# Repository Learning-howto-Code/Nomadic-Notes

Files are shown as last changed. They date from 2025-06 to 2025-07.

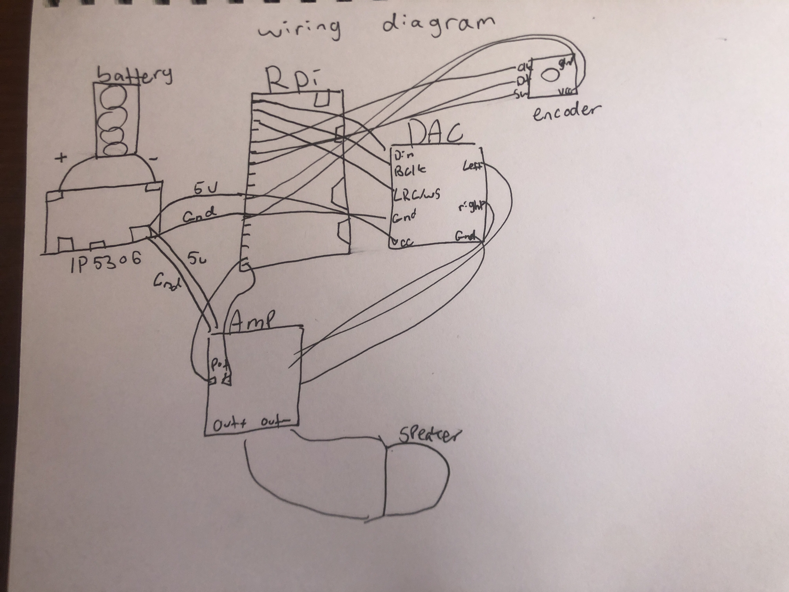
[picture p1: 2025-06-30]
images/wiring_diagram.jpg

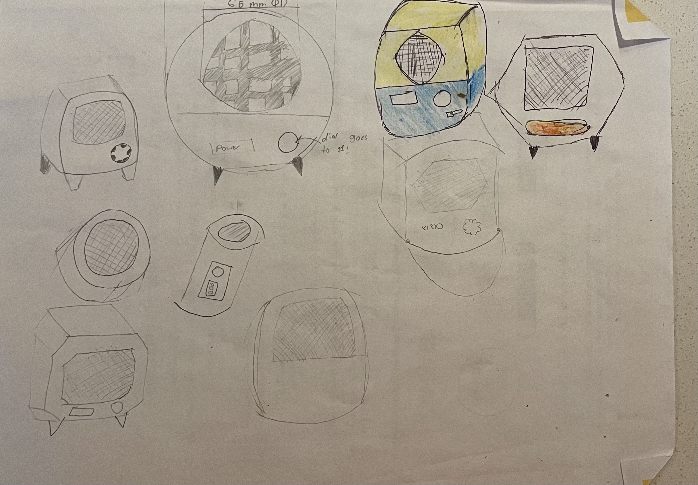
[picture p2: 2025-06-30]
images/sketches.jpg

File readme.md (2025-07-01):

# Nomadic Notes

Nomadic Notes is the first ever pair of open source portable speakers. Nomadic notes are based around a Raspberry Pi Zero 2 W and support the following:

- Airplay  
- Bluetooth Audio  
- Stereo Audio  
- A light, portable design  
- A design-forward approach  

This project is being made for and funded by Hack Club's Highway program.
For any issues or questions, email me at jaketorohopkins@icloud.com, or DM me in the slack at Jake Hopkins
View the BOM in google sheets here for live updates: https://docs.google.com/spreadsheets/d/1EUaRx9kYJ8l8ao9sxJfBVqmWhHC3KokLF9yOrveQJRE/edit?gid=0#gid=0

---

## Renderings
DIY Speakers pre-render
DIY_Speakers V3 render

### Wiring Diagram:

wiring_diagram
(Yes, I drew my wiring diagram, it's also writen out in diagram.md)

---

## BOM (Bill of Materials)

| Item | Quantity | Price (Each) | Link | Notes |
|---|---|---|---|---|
| Rpi Zero 2 W | 2 | $20 | Raspberry Pi Zero 2W with Header | Cheapest board that supports Airplay 2 |
| Speaker | 2 | $26 | Dayton Audio ND65-8 | ~65mm wide |
| DAC | 2 | $5 | Adafruit PCM5100 I2S DAC | Currently out of stock, check Aliexpress |
| Amp | 2 | $20 | MAX9744 | 20W stereo, supports up to 14V |
| Batteries | 8 | $2.50 | Samsung 25R 18650 | On sale, 70% off. 3x4 battery setup |
| Micro SD Card | 2 | $2.50 | — | For Raspberry Pi |
| Buck Converter x5 | 1 pack | $3 | Buck Converter | Comes in a 5-pack |
| Rotary Encoder | 1 | $3 | 2-pack | For volume |
| Battery Charging IC | 2 | $4 | USB-C Charging/BMS Board | De-solder USB-A output ports for load wiring |
| Micro JST Connectors  | 1 pack | $3 | JST Connector | Comes in 10-pack; for driver-to-amp wiring |
| Speaker Grilles (opt) | 1 | $7 | — | Optional but recommended |
| Power Kill Switch | 1 pack | $4 | On/Off Switches | 10-pack on AliExpress |

---

**Check out the BOM excel sheet for the hyperlinks for the exact sources I used and recomend
## Filament

- Your choice

---

### Total Estimated Cost: **$195**
This file was edited for readability by AI as google docs didn't export it well

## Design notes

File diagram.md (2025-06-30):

*Generated pariatly wiht the use of AI to improve Clarity
wiring_diagram

Battery → IP5306

Pack + → B+ pad

Pack – → B– pad

IP5306 → System 5 V

SYS/OUT+ → 5 V rail → Pi VCC (5 V pin) & Amp VCC

SYS/OUT– → common GND

Pi → DAC (I²S)

GPIO 10 (MOSI) → DAC DIN

GPIO 9 (MISO) → DAC not used (keep pull‑down)

GPIO 11 (SCLK) → DAC BCLK

GPIO 18 (PCM‑CLK) → DAC LRC/WS

GND → DAC GND

3.3 V → DAC VCC (if needed)

DAC → MAX9744 Amp

DAC L/R line‑out → AMP L+/R+

DAC GND → AMP GND

Amp → Speaker

AMP OUT+ / OUT– → Speaker ± terminals

Rotary Encoder → Pi

Encoder CLK → Pi GPIO 17 (for example)

Encoder DT → Pi GPIO 27

Encoder SW (push‑button) → Pi GPIO 22

+5 V → Encoder VCC

GND → Encoder GND

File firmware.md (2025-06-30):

I am using shairport sync, so there is no custom firmware. it is based off of this turorial 
https://www.xda-developers.com/build-airplay-receiver-using-raspberry-pi/
Once I get my pot and stuff I will have to wirght a little bit of python but it's very trivial, just reading and writing to 3 gpio pins

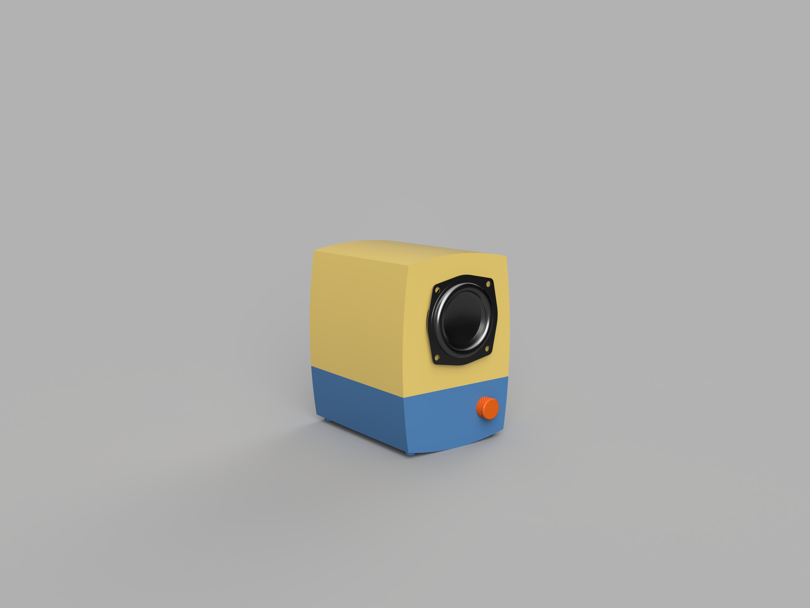
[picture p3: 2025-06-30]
images/DIY_Speakers final renderpng.png

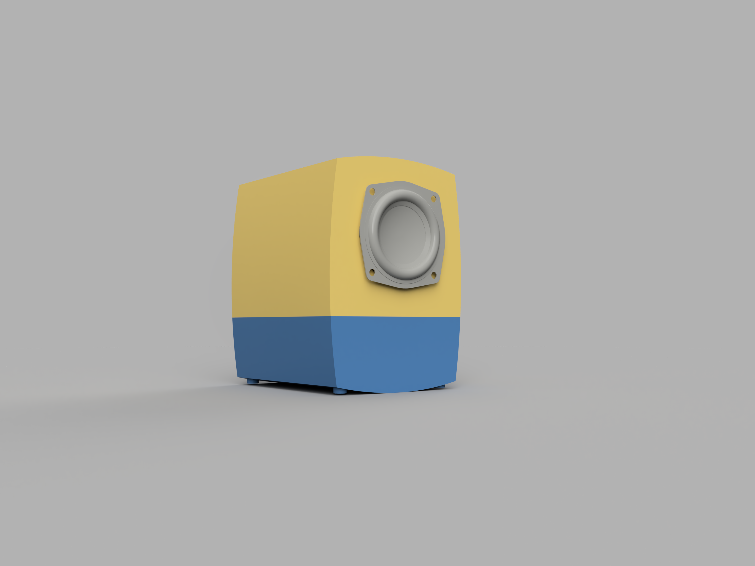
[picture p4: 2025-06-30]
images/DIY_Speakers V3 render.png

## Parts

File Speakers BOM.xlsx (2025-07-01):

Low range~120$ For pair
Item | Quantity | Price(Each) | Link | Notes
Rpi zero 2 W | 2 | 20 | Raspberry Pi Zero 2W with Header (https://www.adafruit.com/product/6008) | cheepest board that supports airplay 2
Speaker | 2 | 26 | Dayton Audio ND65-8 2-1/2" Aluminum Cone Full-Range Neo Driver 8 Ohm (https://www.amazon.com/gp/product/B0042GWIZI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) | From this video, ~ 65mm wide (https://www.youtube.com/watch?v=a43LXqRwQC8&list=PLOJU8YJjFwGOeh6BgCWVhZf5HSkfVPVP3&index=4)
DAC | 2 | 5 | Adafruit PCM5100 I2S DAC with Line Level Output - 100dB SNR (https://www.adafruit.com/product/6251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) | Currently out of stock, check on aliexpress
Amp | 2 | 20 | Stereo 20W Class D Audio Amplifier - MAX9744 (https://www.adafruit.com/product/1752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) | shiping is 6$, comes in 5 days, can take in up to 14 volts
Batteries | 8 | 2.5 | Samsung 25R 18650 2500mAh 20A Battery (https://www.18650batterystore.com/products/samsung-25r-18650?variant=37119890063511) | On sale, 70% off. will do 3x4 battery setup
micro sd card | 2 | 2.5 | Micro SD card (https://www.aliexpress.us/item/3256806796589355.html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) | For Rpi's
Buck converter x5 | 1 | 3 | Buck Converter (https://www.aliexpress.us/item/3256808133588550.html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) | comes in a 5 pack
Rotary Encoder | 1 | 3 | 2 pack (https://www.aliexpress.us/item/3256808610376268.html?pdp_ext_f=%7B%22order%22%3A%22450%22%7D) | for volume
Battery Charging IC | 2 | 4 | Usb-C charging/BMS board (https://www.aliexpress.us/item/2255800387899850.html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) | You need to de-solder the usb-A output ports in order to solder your loads onto them
Micro JST connectors | 1 | 3 | JST connector (https://www.aliexpress.us/item/3256803204628036.html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) | comes in a 10 pack, used for connecting driver to amp, and amp to buck converter
Speaker Grilles(optional) | 1 | 7 | optional grilles (https://www.amazon.com/MEETOOT-Rolled-Loudspeaker-Mounting-Speaker/dp/B09L7LBTGV) | Not necesary, but recomended unless you like the look of the raw speaker cone
power kill switch | 1 | 4 | 10 pack of on/off switches (https://www.aliexpress.us/item/3256808310696141.html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) | This was the cheepest one on Aliexpress
M3 screws | 4 | 50 cents |  | I found them in person at ace or other hardware store
Filament |  |  |  | Your choice
Total |  | 195

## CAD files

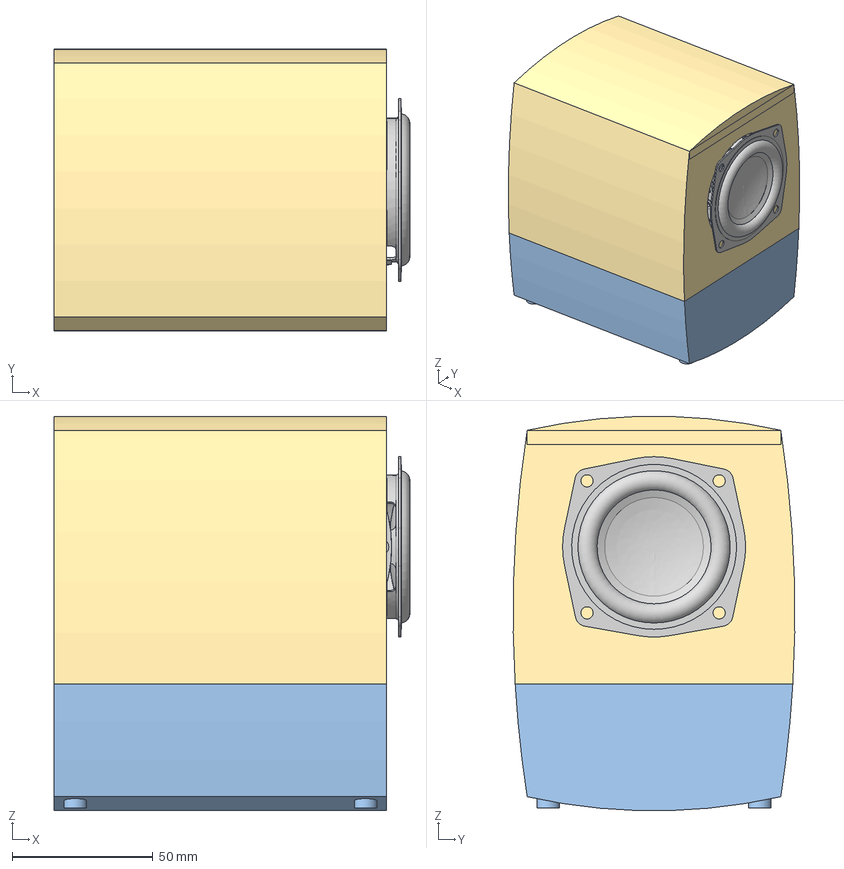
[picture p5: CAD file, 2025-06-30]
CAD_Files/Step/DIY Speakers v4.step
126.2 x 99.9 x 139.8 mm
Speaker Housing
Driver
Driver box
Pot

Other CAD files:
CAD_Files/F3d/DIY Speakers v4.f3d

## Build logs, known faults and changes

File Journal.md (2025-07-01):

## **Total Time Spent:**

## \*I started this project on vacation so for the first few days I didn’t get nearly as much done as you might expect, also I didn’t work on it everyday, so I only included the days I worked on it

# Days 1&2- Gathering intel

	I’ve found that a lot of people 3D print, make pcb’s, and create impressive robotics projects. Some people, especially on youtube create art or even full projects with 3d printing, but very few people create the instructables type projects from a design perspective. Here’s what I mean. If you look online dozens of people have created a weather box for their desk, allowing them to see the weather at a glance. I think this is an awesome project, and will introduce you to electronics, CAD, and integration hell. But they're all just boxes\! For example look at this awesome project by [educ8s on Instructables](https://www.instructables.com/Arduino-ESP32-Color-E-Paper-Weather-Station/). It looks great, and you can really tell that you put a lot of hard work into it. But the actual 3d printed enclosure is quite mundane and is just a box with some light fillets. Just to be clear, I’m not throwing shade on anybody, and especially not educ8s, I think what he did is really cool, but it’s been done before, and not what **I** want to do.  
	So I didn’t. I approached my project from the very beginning as a design project. Yes, there are complicated electronics, enclosures and firmware, but I wanted my project to stand out because it looked good, and for that to be the reason to build it.  
	On days one and two I searched and read nearly every guide on the internet for custom, DIY, portable speakers and a few things stood out to me. Everyone made boomboxes- or at least some version of a big plywood box that housed all the electronics and speakers, meaning that they could never achieve stereo sound nor were they very portable. Also no one made airplay2 speakers. While a proprietary Apple protocol, all of my friends and family, including myself, have iPhones, and if I were to use this speaker regularly it would have to support this super easy way to connect, along with bluetooth. Finally none of them looked good. There were some really nice designs, they weren’t what I was looking for- either they were wood veneer or a retro design. I spent the next few days thinking about how to make my speakers shine.  
 
**Time Spent: \~2 hours**

# Days 3 & 4 \- Ideation

From taking 3d sculpture last year in school I learned a lot about planning out a project, and I think it shows how I approached this project that I started with an element of art, sketches; Thumbnail sketches are an easy way to quickly get your ideas on paper, and I love them as their not inhibited by my art skills. From looking at JBl’s website I already knew that I wanted to put a playful spin on the [JBl clip 5](https://www.jbl.com/bluetooth-speakers/CLIP-5.html). I liked the form factor, but knew that it would be near impossible to fit all of my components into such a small form factor, so I decided to take the playful curves and design language of the clip 5 and put a spin on bookshelf speakers. Starting with the shape of a bookshelf speaker, I first thought about putting heavy chamfers on the corners, as seen in the bottom left corner; I decided against this though as chamfers give more of an industrial feel, and suit metal more, which isn’t what I wanted for this project, even though I think it would look really good. I then questioned the form factor, wondering if a tube-like design like the [Charge 5](https://www.jbl.com/bluetooth-speakers/CLIP-5.html) might be better. I also decided against this though, as it has been done before and doesn’t stand out in the way I want it to. You can see that I then settled in on my final design, although it sort of looks like a minion in this drawing. My final design incorporates lots of swooping arches in order to give my speakers the playful look I was going for. In the drawing I played around with color schemes but decided on black and white with orange accents, all PLA.  
sketches
**Time Spent: \~1.5 hours**

# Days 5 & 6 \- Components Sourcing


	Today I started my [BOM](https://docs.google.com/spreadsheets/d/1EUaRx9kYJ8l8ao9sxJfBVqmWhHC3KokLF9yOrveQJRE/edit?gid=0#gid=0) and sourcing components. After watching videos and reading tutorials I started to get a sense of what components people were using. I finally landed on the Dayton Audio ND65-8 2-1/2" driver from [this video by DIY Perks](https://www.youtube.com/watch?v=a43LXqRwQC8&list=PLOJU8YJjFwGOeh6BgCWVhZf5HSkfVPVP3&index=4&pp=iAQB) as it is a full range driver, eliminating the need for a crossover, while still being quite capable(80-20,000 hertz range). As aforementioned, one of my design requirements was that it had airplay 2, leading me to use a Raspberry Pi 2 W(Rpi) instead of a microcontroller or bluetooth module. The DAC is an important component, since even though the Rpi has built in DAC it’s designed for reading data from the GPIO pins, and isn’t audio grade. I’ve never built a battery pack before, and am deciding to start the CAD first, before sourcing my BMS and charging module.  
**Time Spent\~ 3 hours**

# Days 7 & 8 \- Hoping into CAD
DIY Speakers pre-render

I use Fusion 360, as I find it’s the perfect tool for these types of projects, plus they hook up students with a free license and cloud computer. After calculating the column for the driver box, I built up the enclosure around it. I designed the whole thing to be assembled with M3 screws, and to print without supports. Before finishing the model I decided to source the last components for my battery pack.

*Render of my mostly complete model*  
**Time Spent \~2 hours**

# Day 9- The battery pack

Today I worked on the battery pack for my speakers. I knew that I wanted to use 18650 cells as I had worked with them before and I found out from the slack that [18650batterystore.com](http://18650batterystore.com) is one of the cheapest places to buy legit cells. After doing some basic math I concluded that my speaker would draw a little less that 5 watts at peak power( 2 watts for the Rpi, 2 watts for the driver, plus some loss along the way). I decided on 4 cells in parallel for an output of 3.7 volts nominal at 10 amps, or around 37 watts. This should give the speakers approximately 7 hours of run time- plenty for an all day battery. After looking at battery packs designed by other people I saw [this super simple one by Great Scott.](https://www.instructables.com/Building-a-USB-Type-C-PD-Powerbank-the-Super-Simpl/) I decided to use the charging IC from it since it would safely charge the 18650 cells, stepped the 3.7 volts up to 5 and charged via Usb-C.  
**Time Spent\~1 hour**

# Day 10- Finishing up CAD
DIY_Speakers final renderpng

Today I finished up my CAD design. I added print in place feet to the base of my design and made some other small tweaks. Since I had finalized my battery system I also added things like my rotary encoder and kill switch into the design. Thinking about putting the finishing touches on my design and the acoustic properties of my driver box I studied how high end speakers, like the 2,000$ [Sonus Faber Sonneto’s](https://www.sonusfaber.com/en/products/sonetto-i) use asymmetrical design to dampen resonant frequency and incorporated asymmetrical draft angles into my design to help with frequencies bouncing back and forth between parallel faces. After rendering out my design from a few different angles I was happy with it, and getting ready to submit my project

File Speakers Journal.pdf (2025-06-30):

### Total Time Spent:

### *I started this project on vacation so for the first few days I didn’t get nearly as much done as you might expect, also I didn’t work on it everyday, so I only included the days I worked on it

## Days 1&2- Gathering intel

I’ve found that a lot of people 3D print, make pcb’s, and create impressive robotics projects. Some people, especially on youtube create art or even full projects with 3d printing, but very few people create the instructables type projects from a design perspective. Here’s what I mean. If you look online dozens of people have created a weather box for their desk, allowing them to see the weather at a glance. I think this is an awesome project, and will introduce you to electronics, CAD, and integration hell. But they're all just boxes! For example look at this awesome project by educ8s on Instructables. (https://www.instructables.com/Arduino-ESP32-Color-E-Paper-Weather-Station/) It looks great, and you can really tell that you put a lot of hard work into it. But the actual 3d printed enclosure is quite mundane and is just a box with some light fillets. Just to be clear, I’m not throwing shade on anybody, and especially not educ8s, I think what he did is really cool, but it’s been done before, and not

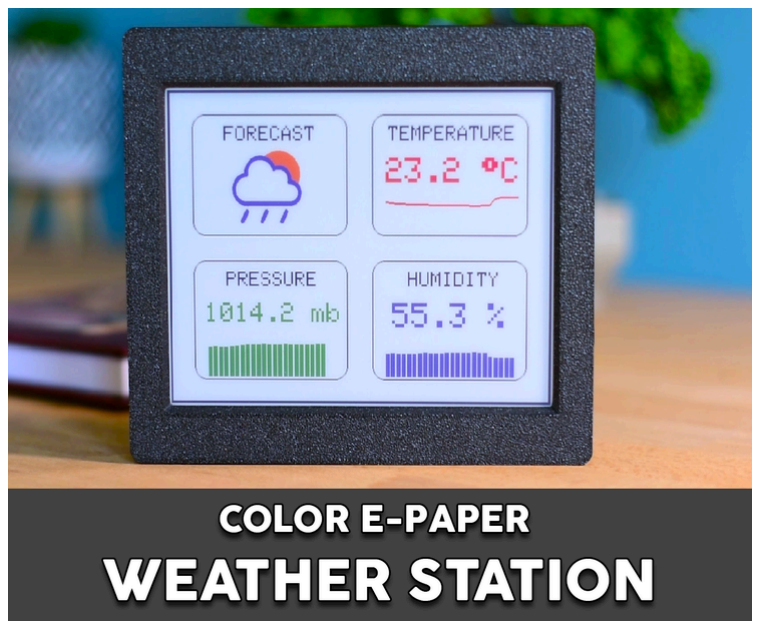
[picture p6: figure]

what I want to do.
So I didn’t. I approached my project from the very beginning as a design project. Yes, there are complicated electronics, enclosures and firmware, but I wanted my project to stand out because it looked good, and for that to be the reason to build it.
On days one and two I searched and read nearly every guide on the internet for custom, DIY, portable speakers and a few things stood out to me. Everyone made boomboxes- or at least some version of a big plywood box that housed all the electronics and speakers, meaning that they could never achieve stereo sound nor were they very portable. Also no one made airplay2 speakers. While a proprietary Apple protocol, all of my friends and family, including myself, have iPhones, and if I were to use this speaker regularly it would have to support this super easy way to connect, along with bluetooth. Finally none of them looked good. There were some really nice designs, they weren’t what I was looking for- either they were wood veneer or a retro design. I spent the next few days thinking about how to make my speakers shine.
Time Spent: ~2 hours

## Days 3 & 4 - Ideation

From taking 3d sculpture last year in school I learned a lot about planning out a project, and I think it shows how I approached this project that I started with an element of art, sketches; Thumbnail sketches are an easy way to quickly get your ideas on paper, and I love them as their not inhibited by my art skills. From looking at JBl’s website I already knew that I wanted to put a playful spin on the JBl clip 5. (https://www.jbl.com/bluetooth-speakers/CLIP-5.html) I liked the form factor, but knew that it would be near impossible to fit all of my components into such a small form factor, so I decided to take the playful curves and design language of the clip 5 and put a spin on bookshelf speakers. Starting with the shape of a bookshelf speaker, I first thought about putting heavy chamfers on the corners, as seen in the bottom left corner; I decided against this though

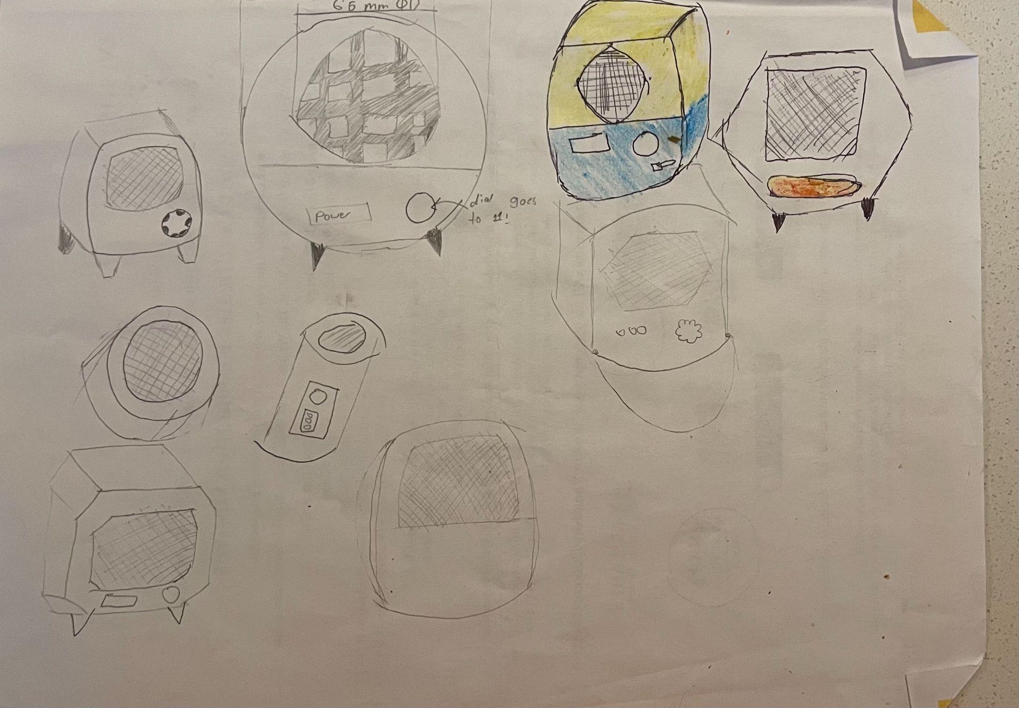
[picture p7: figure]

as chamfers give more of an industrial feel, and suit metal more, which isn’t what I wanted for this project, even though I think it would look really good. I then questioned the form factor, wondering if a tube-like design like the Charge 5 (https://www.jbl.com/bluetooth-speakers/CLIP-5.html) might be better. I also decided against this though, as it has been done before and doesn’t stand out in the way I want it to. You can see that I then settled in on my final design, although it sort of looks like a minion in this drawing. My final design incorporates lots of swooping arches in order to give my speakers the playful look I was going for. In the drawing I played around with color schemes but decided on black and white with orange accents, all PLA.
Time Spent: ~1.5 hours

## Days 5 & 6 - Components Sourcing

Today I started my BOM (https://docs.google.com/spreadsheets/d/1EUaRx9kYJ8l8ao9sxJfBVqmWhHC3KokLF9yOrveQJRE/edit?gid=0#gid=0) and sourcing components. After watching videos and reading tutorials I started to get a sense of what components people were using. I finally landed on the Dayton Audio ND65-8 2-1/2" driver from this video by DIY Perks (https://www.youtube.com/watch?v=a43LXqRwQC8&list=PLOJU8YJjFwGOeh6BgCWVhZf5HSkfVPVP3&index=4&pp=iAQB) as it is a full range driver, eliminating the need for a crossover, while still being quite capable(80-20,000 hertz range). As aforementioned, one of my design requirements was that it had airplay 2, leading me to use a Raspberry Pi 2 W(Rpi) instead of a microcontroller or bluetooth module. The DAC is an important component, since even though the Rpi has built in DAC it’s designed for reading data from the GPIO pins, and isn’t audio grade. I’ve never built a battery pack before, and am deciding to start the CAD first,

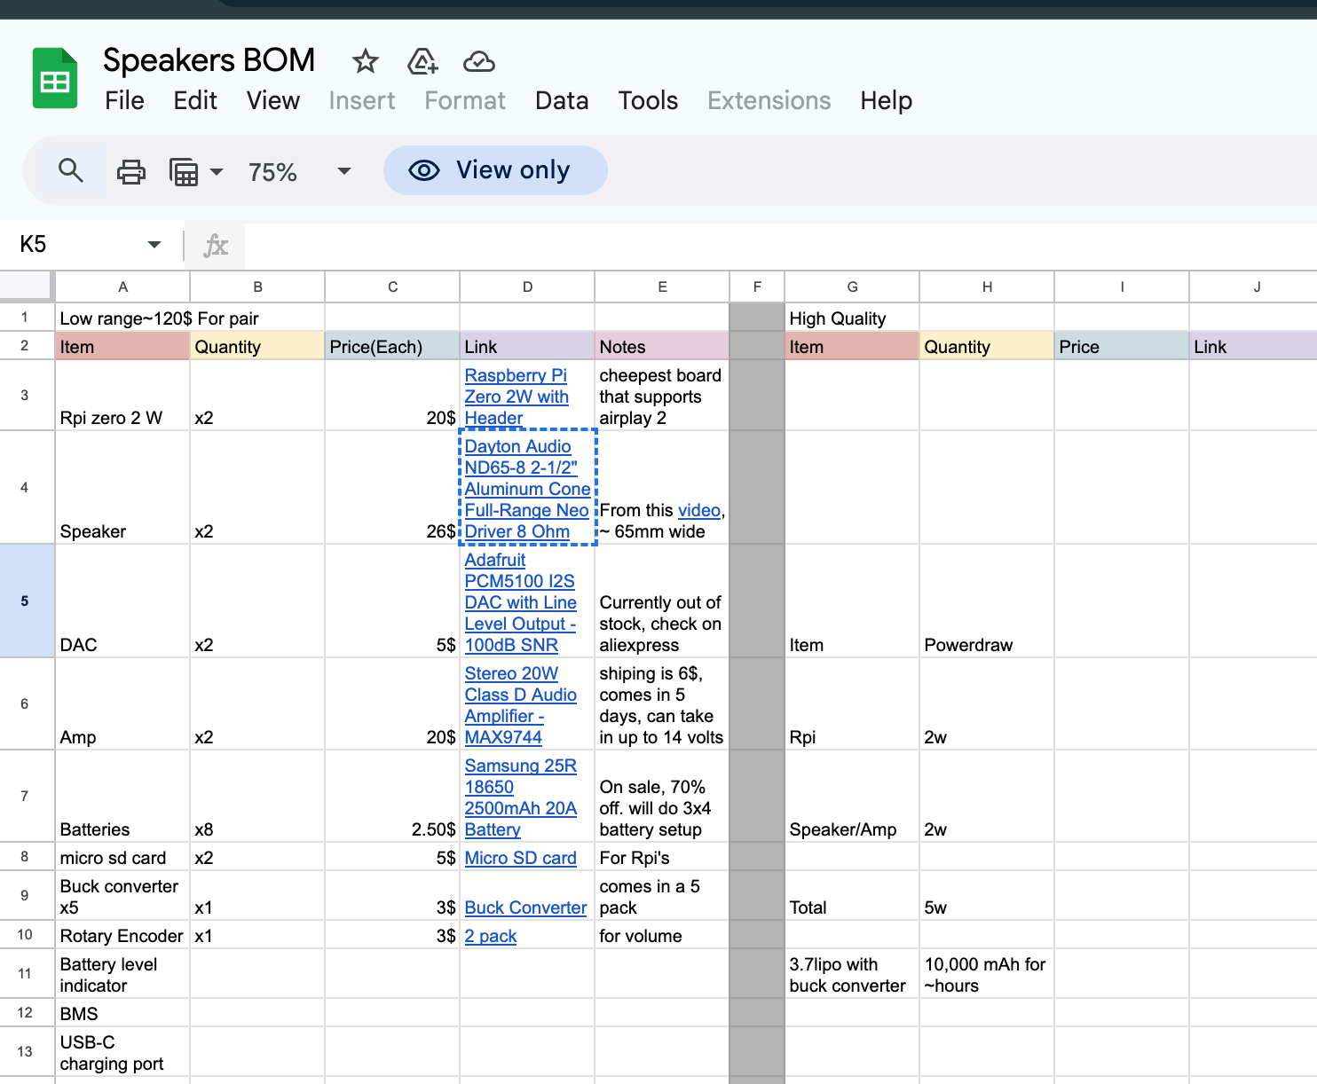
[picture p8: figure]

before sourcing my BMS and charging module. Time Spent~ 3 hours

## Days 7 & 8 - Hoping into CAD

I use Fusion 360, as I find it’s the perfect tool for these types of projects, plus they hook up students with a free license and cloud computer. After calculating the column for the driver box, I built up the enclosure around it. I designed the whole thing to be assembled with M3 screws, and to print without supports. Before finishing the model I decided to source the last components for my battery pack.

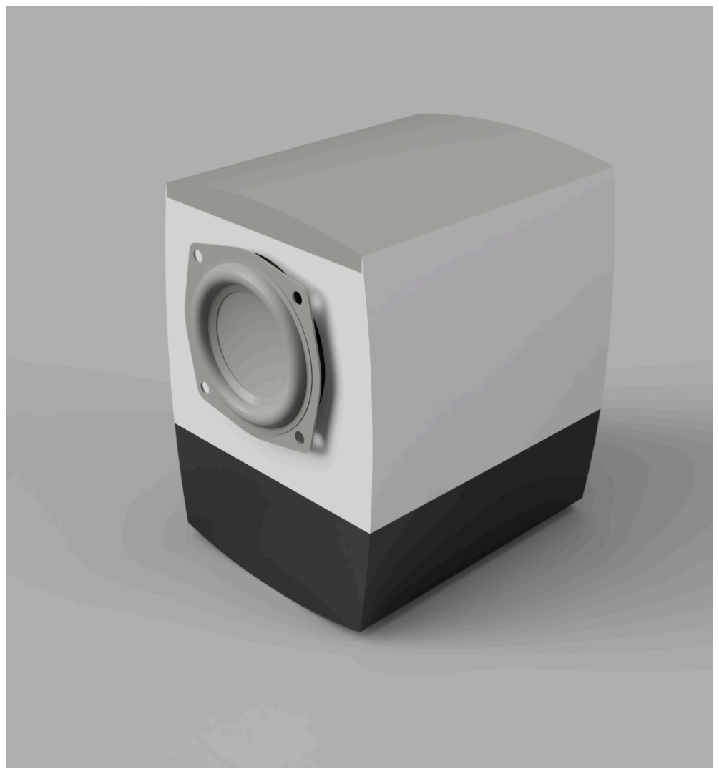
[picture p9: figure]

Render of my mostly complete model
Time Spent ~2 hours

## Day 9- The battery pack

Today I worked on the battery pack for my speakers. I knew that I wanted to use 18650 cells as I had worked with them before and I found out from the slack that 18650batterystore.com is one of the cheapest places to buy legit cells. After doing some basic math I concluded that my speaker would draw a little less that 5 watts at peak power( 2 watts for the Rpi, 2 watts for the driver, plus some loss along the way). I decided on 4 cells in parallel for an output of 3.7 volts nominal at 10 amps, or around 37 watts. This should give the speakers approximately 7 hours of run time- plenty for an all day battery. After looking at battery packs designed by other people I saw this super simple one by Great Scott. (https://www.instructables.com/Building-a-USB-Type-C-PD-Powerbank-the-Super-Simpl/) I decided to use the charging IC from it since it would safely charge the 18650 cells, stepped the 3.7 volts up to 5 and charged via Usb-C.
Time Spent~1 hour

## Day 10- Finishing up CAD

Today I finished up my CAD design. I added print in place feet to the base of my design and made some other small tweaks. Since I had finalized my battery system I also added things like my rotary encoder and kill switch into the design. Thinking about putting the finishing touches on my design and the acoustic properties of my driver box I studied how high end speakers, like the 2,000$ Sonus Faber Sonneto’s (https://www.sonusfaber.com/en/products/sonetto-i) use asymmetrical design to dampen resonant frequency and incorporated asymmetrical draft angles into my design to help with frequencies bouncing back and forth between parallel faces. After rendering out my design from a few different angles I was happy with it, and getting ready to submit my project

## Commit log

2025-06-30 addded in CAD files + renders
    [DIY Speakers v4.f3d, DIY Speakers v4.step]
2025-07-01 updated BOM.csv
    [Speakers BOM.xlsx]
